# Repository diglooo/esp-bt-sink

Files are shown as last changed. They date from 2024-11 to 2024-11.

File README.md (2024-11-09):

# ESP32 A2DP audio receiver
This is a project for an ESP32 based A2DP bluetooth receiver. Analog output is generated by an external I2S DAC.
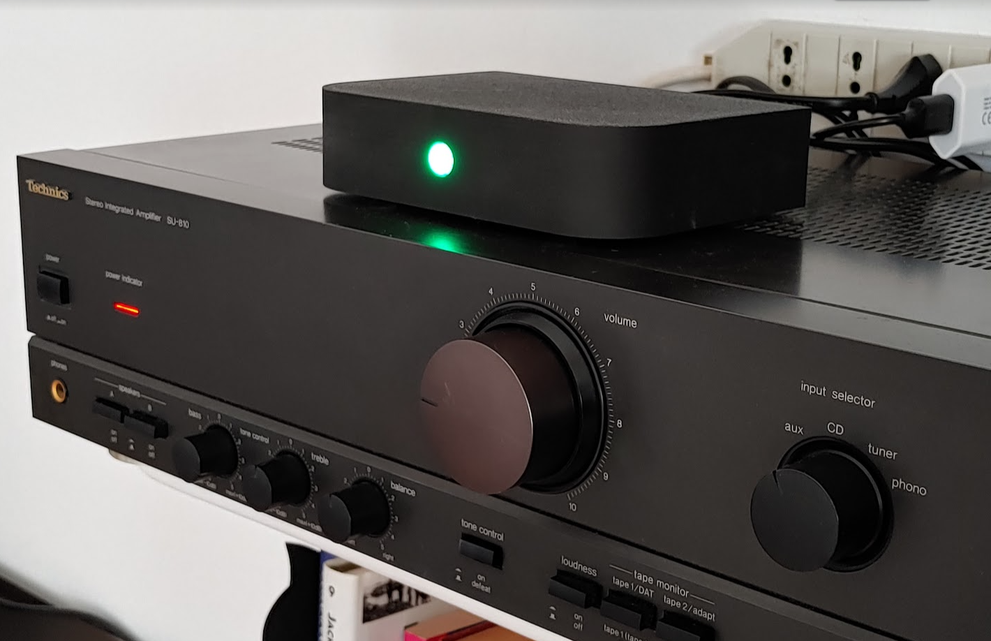
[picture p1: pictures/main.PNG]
Receiver box

Features:
 - Simple PlatformIO project
 - Based on the A2DP library from [ESP32-A2DP](https://github.com/pschatzmann/ESP32-A2DP)
 - Standard SBC codec. 
	 - Supporting AptX and AAC [is possible](https://github.com/cfint/esp32-a2dp-sink) but requires vast changes to the project and has a low impact on sound quality.
 - PCM5102A I2S DAC (buy on Amazon)
 - ESP32-WROOM-32 in a Devkitc-V4 (buy on Amazon)
 - User button with RGB LED (WS2812b) for secure pairing and status.
 - Power amplifier control: turn off a relay when nobody is connected or when playback is inactive for too long.
 - 3D printable enclosure made with PTC Creo Parametric 7 (STEP files available)

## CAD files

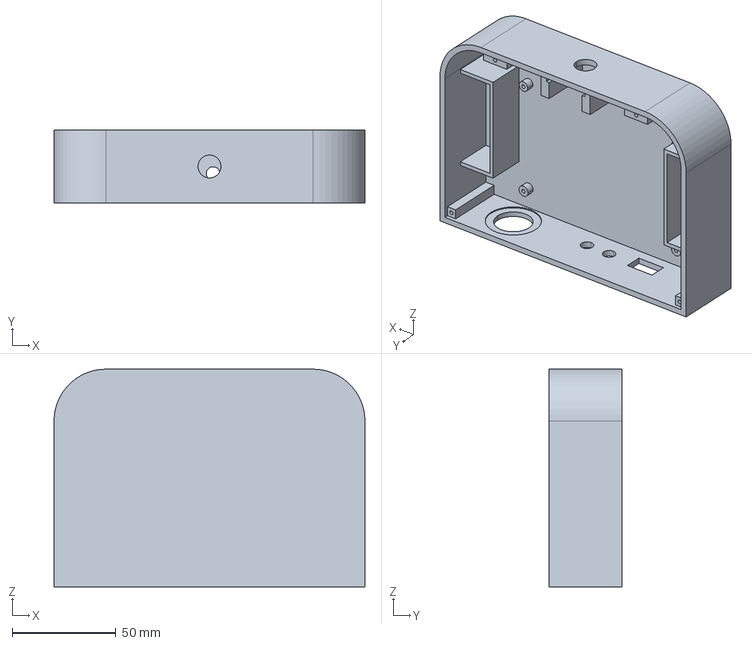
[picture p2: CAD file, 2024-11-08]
mec/STEP/box_base.stp
150.0 x 35.0 x 105.0 mm

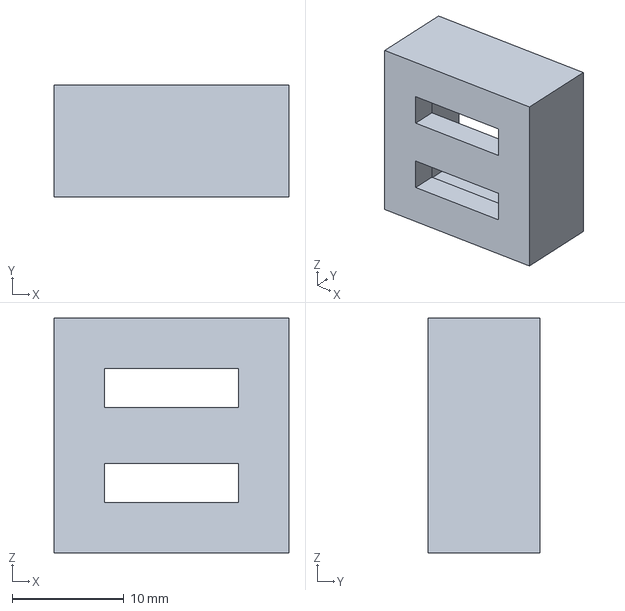
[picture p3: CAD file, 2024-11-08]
mec/STEP/led_button_endcap.stp
21.0 x 10.0 x 21.0 mm

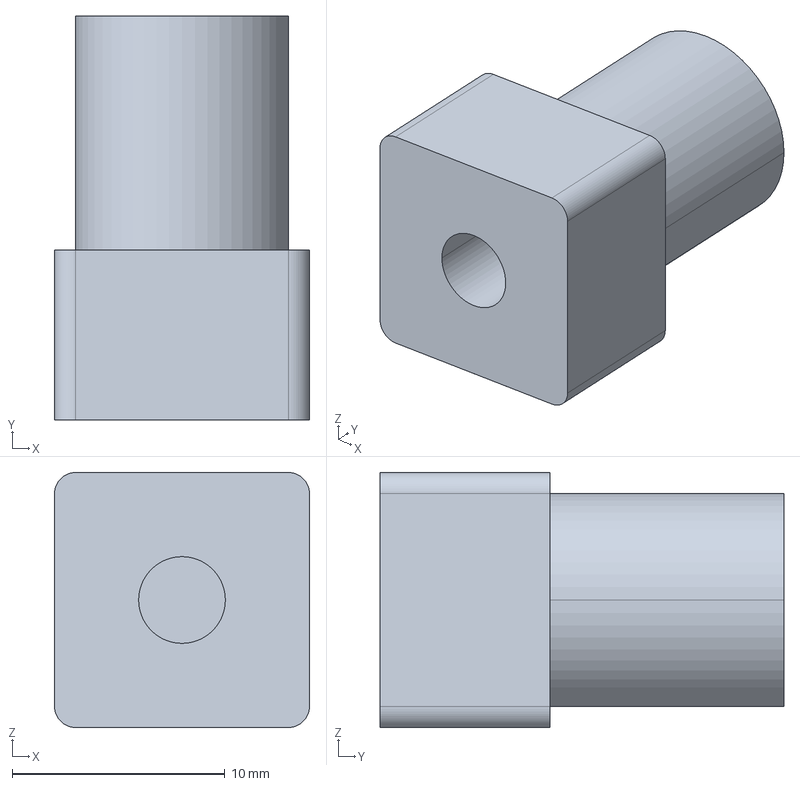
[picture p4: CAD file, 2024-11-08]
mec/STEP/led_button_btn.stp
12.0 x 19.0 x 12.0 mm

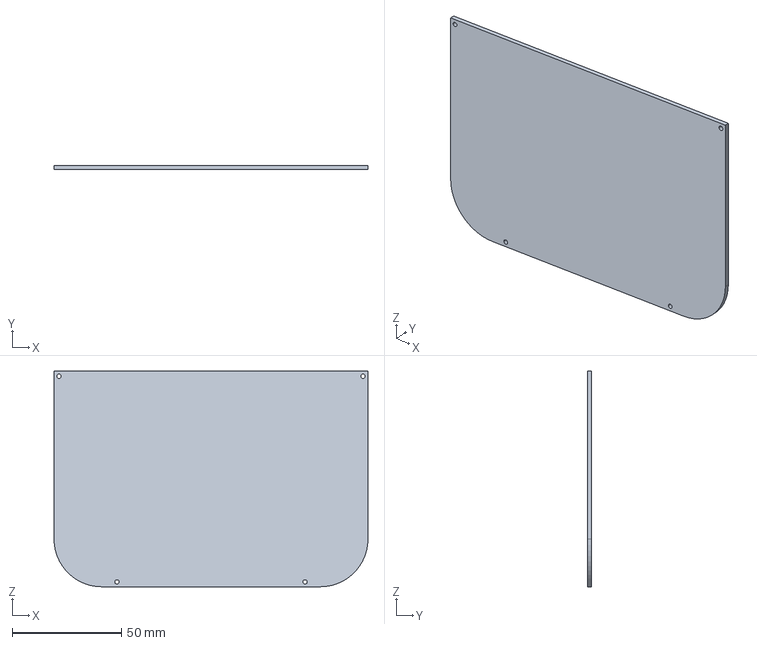
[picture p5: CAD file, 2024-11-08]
mec/STEP/cap.stp
143.6 x 2.00 x 98.6 mm

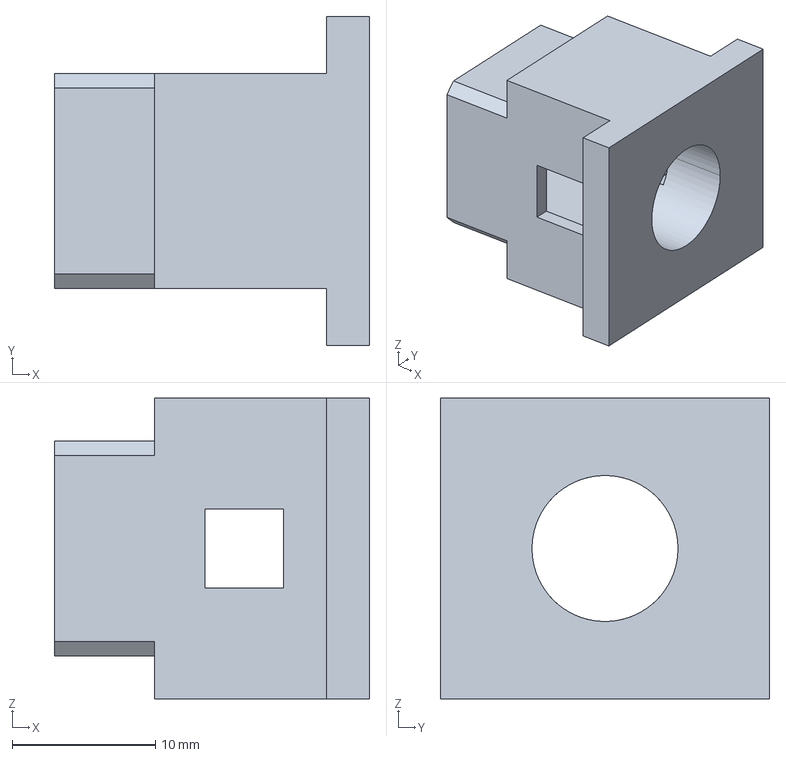
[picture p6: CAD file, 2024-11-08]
mec/STEP/led_button_base.stp
22.0 x 23.0 x 21.0 mm

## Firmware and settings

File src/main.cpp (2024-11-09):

#include "AudioTools.h"
#include "BluetoothA2DPSinkQueued.h"
#include <Bonezegei_WS2812.h>

// connections
// On PCM5102A board, you must bridge SCK on PCB
#define PIN_BCK 26  // PCM5102A BCK
#define PIN_DATA 27 // PCM5102A DIN
#define PIN_WS 25   // PCM5102A LCK
#define PIN_PAIR_BUTTON 13
#define PIN_RELAY 14
#define PIN_LED_DATA 15

// settings
#define NO_SOUND_TIMEOUT_MS 60000
#define BUTTON_PAIRING_WINDOW_MS 10000
#define BLUETOOTH_DEVICE_NAME "Cuccumella"

// state machine
#define APP_STA_INIT 0
#define APP_STA_DISCONNECTED 1
#define APP_STA_PAIRING 2
#define APP_STA_CHECK_PAIRING 3
#define APP_STA_PAIRING_FAILED 4
#define APP_STA_CONNECTED 5
#define LED_QUANTITY 2

// param WS2812 pin
Bonezegei_WS2812 rgb_led(PIN_LED_DATA, LED_QUANTITY);
int relay_status = 0;
int connected = 0, connected_old = 0;
int cnt = 0;
int pairing_millis = 0;
long millisNow = 0;
long user_button_millis = 0;
long last_play_millis = 0;
long last_blink_millis = 0;
uint32_t blink_led_color = 0;
uint32_t static_led_color = 0;
int blink_var = 0;
int user_ack = 0;
int standby = 0;
int APP_STATE = APP_STA_INIT;

I2SStream i2s;
BluetoothA2DPSink a2dp_sink(i2s);

void avrc_metadata_callback(uint8_t id, const uint8_t *text)
{
    Serial.printf("AVRC data 0x%x = %s\n", id, text);
}

void audio_data_received_callback()
{
    last_play_millis = millis();
}

void led_control()
{
    if (millisNow - last_blink_millis > 250)
    {
        last_blink_millis = millisNow;
        if (blink_led_color)
        {
            if (blink_var)
                rgb_led.fill(blink_led_color);
            else
                rgb_led.fill(0x00000000);
            blink_var = !blink_var;
        }
        else
        {
            blink_var = 1;
        }
    }

    if (static_led_color)
        rgb_led.fill(static_led_color);

    if (!static_led_color && !blink_led_color)
        rgb_led.fill(0x00000000);
}

void setup()
{
}

void loop()
{
    millisNow = millis();
    connected_old = connected;
    connected = a2dp_sink.is_connected();

    switch (APP_STATE)
    {
    case APP_STA_INIT:
    {
        pinMode(PIN_RELAY, OUTPUT);
        pinMode(PIN_PAIR_BUTTON, INPUT_PULLUP);
        //Serial.println("APP_STA_INIT");
        Serial.begin(115200);
        rgb_led.begin();
        rgb_led.fill(0x000000);

        audio_tools::I2SConfig cfg = i2s.defaultConfig();
        cfg.pin_bck = PIN_BCK;
        cfg.pin_data = PIN_DATA;
        cfg.pin_ws = PIN_WS;
        i2s.begin(cfg);

        a2dp_sink.set_avrc_metadata_attribute_mask(ESP_AVRC_MD_ATTR_TITLE | ESP_AVRC_MD_ATTR_ARTIST | ESP_AVRC_MD_ATTR_ALBUM);
        a2dp_sink.set_avrc_metadata_callback(avrc_metadata_callback);
        a2dp_sink.set_on_data_received(audio_data_received_callback);
        a2dp_sink.activate_pin_code(true);
        a2dp_sink.start(BLUETOOTH_DEVICE_NAME);
        APP_STATE = APP_STA_DISCONNECTED;
        break;
    }

    case APP_STA_DISCONNECTED:
    {
        //Serial.println("APP_STA_DISCONNECTED");

        digitalWrite(PIN_RELAY, 0);
        if (a2dp_sink.pin_code())
        {
            APP_STATE = APP_STA_PAIRING;
        }
        if (connected)
        {
            APP_STATE = APP_STA_CONNECTED;
            pairing_millis = 0;
        }
        break;
    }

    case APP_STA_PAIRING:
    {
        //Serial.println("APP_STA_PAIRING");
        if (user_ack)
        {
            a2dp_sink.confirm_pin_code();
            APP_STATE = APP_STA_CHECK_PAIRING;
        }
        if (a2dp_sink.pin_code() == 0)
        {
            user_button_millis = 0;
            APP_STATE = APP_STA_DISCONNECTED;
        }
        break;
    }

    case APP_STA_CHECK_PAIRING:
    {
        //Serial.println("APP_STA_CHECK_PAIRING");
        if (connected)
        {
            APP_STATE = APP_STA_CONNECTED;
            pairing_millis = 0;
            last_play_millis = millis();
        }
        if (pairing_millis++ > 10 || a2dp_sink.pin_code() == 0)
        {
            APP_STATE = APP_STA_PAIRING_FAILED;
        }
        break;
    }

    case APP_STA_PAIRING_FAILED:
    {
        //Serial.println("APP_STA_PAIRING_FAILED");
        user_button_millis = 0;
        APP_STATE = APP_STA_DISCONNECTED;
        break;
    }

    case APP_STA_CONNECTED:
    {
        //Serial.println("APP_STA_CONNECTED");
        digitalWrite(PIN_RELAY, !standby);
        if (!connected)
        {
            APP_STATE = APP_STA_DISCONNECTED;
            user_button_millis = 0;
        }
        break;
    }
    }

    if (!digitalRead(PIN_PAIR_BUTTON))
    {
        user_button_millis = millisNow;
        last_play_millis = millis();
    }
    user_ack = (millisNow - user_button_millis < BUTTON_PAIRING_WINDOW_MS) && user_button_millis>0;
    standby = !(millisNow - last_play_millis < NO_SOUND_TIMEOUT_MS);

    if (user_ack)
    {
        static_led_color = 0;
        blink_led_color = 0xFDF8E2;
    }

    if (!user_ack && APP_STATE == APP_STA_DISCONNECTED)
    {
        static_led_color = 0;
        blink_led_color = 0;
    }

    if (APP_STATE == APP_STA_CONNECTED)
    {
        static_led_color = 0x0FFF0F;
        blink_led_color = 0;
    }

    if (APP_STATE == APP_STA_PAIRING && !user_ack)
    {
        static_led_color = 0;
        blink_led_color = 0xFDF8E2;
    }

    if (APP_STATE == APP_STA_CONNECTED && standby)
    {
        static_led_color = 0x0F0A00;
        blink_led_color = 0;
    }

    led_control();
    delay(50);
}

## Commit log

2024-10-31 bt state machine
    [RelayModule_(1).STEP, box_base.stp]
2024-11-04 added ws2812b led
    [1825910-6.step]
2024-11-08 finished button
    [box_base.stp, cap.stp, led_button_base.stp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]
2024-11-08 led and button fix
    [main.cpp]
2024-11-09 fix state machine
    [1825910-6.step, RelayModule_(1).STEP]
